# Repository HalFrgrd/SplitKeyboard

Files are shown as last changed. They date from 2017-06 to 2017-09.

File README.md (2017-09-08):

# SplitKeyboard

This is a split DIY custom keyboard loosely based on:
  * Ultimate Hacking Keyboard (interlocking ability)
  * General ten key less design
  * Preonic (I liked how the bottom row was nearly all 1u)

It is also interlocking with magnets to snap it together.
There are thumb arrow keys.
[See here for images](http://imgur.com/a/XaVwF)

**Table of Contents**  *generated with [DocToc](http://doctoc.herokuapp.com/)*

  - [How a split keyboard connects both halves](#how-a-split-keyboard-connects-both-halves)
    - [Basic concepts](#basic-concepts)
    - [Wiring between the two halves](#wiring-between-the-two-halves)
  - [Sourcing your parts](#sourcing-your-parts)
  - [Build guide](#build-guide)
    - [Designing and planning](#designing-and-planning)
    - [Putting it together](#putting-it-together)
      - [General assembly](#general-assembly)
      - [Wiring](#wiring)
  - [Custom firmware](#custom-firmware)
  
### How a split keyboard connects both halves
#### Basic concepts
While researching, I didn't find a comprehensive guide on split keyboard concepts.
These are the ways I learnt it could be done:
  * Having a controller (Teensy or an Arduino) in one half and an IO expander in the other half.
  * Having two controllers, one in each half which communicate via one of two protocols:
    * Serial or
	 * I2C
  * One controller and a bunch of wires between the halves

Controller + IO expander: The way the wiring in any keyboard works is that each row and each column is wired individually to a pin on somekind of controller. Say you have a controller with 20 available pins, your keyboard can have at most 100 keys as you can have 10 rows and 10 columns. If you want more keys, you use and IO expander. An IO expander has a bunch of pins for wiring the rows and columns to and a few special pins that are wired to the controller on the other half of the keyboard. Only two pins are used for communication between the IO expander and the Arduino. special pin condenses all the other pins and can pass all the information from the pins to the controller. So you can have a controller in one half and an IO expander in the other and have only a few wires between the two halves.

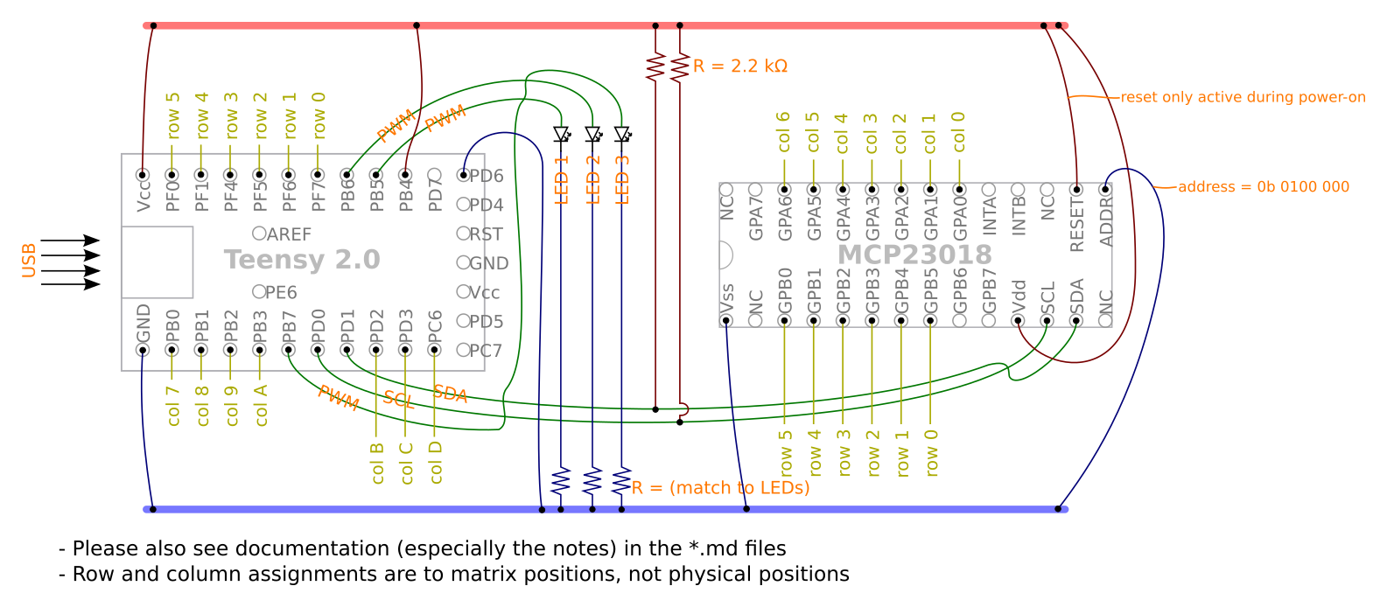
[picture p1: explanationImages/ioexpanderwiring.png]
wiringioexpander


Two controllers: In this method, each half has a controller. The second controller (the one that isn't plugged directly into the computer) acts like a more versatile IO expander. I say more versatile because you can plug the secondary half into the computer or use both halves independently. It can act as a controller when you want it to. I believe that the firmware on the secondary half is used only to forward the signals on to the other half and the keymap that is on this secondary controller doesn't get used. But when you have it plugged into the computer separately, it runs the keymap that you programmed to it. So when it is being used as a secondary half it can behave in one way, but if you use it one its own, it might act as a numpad (or any other custom keymap).

If you have a controller in each half, you have to decide how they communicate with each other; what communication protocol do they use. I have learnt that the two main ones are Serial and I2C. Sparkfun does a great beginner friendly in depth look at them: [serial](https://learn.sparkfun.com/tutorials/serial-communication) and [I2C](https://learn.sparkfun.com/tutorials/i2c). On a side note, Sparkfun tells you a list of suggested topics before reading the chosen topic, so if you want to learn more about the electronics involved, start on Sparkfun. Without going in depth, the main differences are:
  * Serial uses 3 wires and I2C uses 4 (more about this in the next topic)
  * I2C is faster (but not noticeably because no one types that fast)

This is the method I used because an IO expander was going to be about the same cost as another Arduino. I also used serial just because it was easier working with 3 wires. Wiring for both serial and I2C can be found [here](#wiring)

The last (and least 'clean') method is just to have a lot of wires going between the sides. For instance, all the switches in a row on one side would be connected to a wire that goes between the halves and connects to all the switches on that half and then to the controller. 

The method you will affect the choice in wires that you have to make.
#### Wiring between the two halves
For the first two methods listed above, you will need a maximum of 4 wires:
  * One for ground
  * One for power
  * One/two for communication depending on protocol.

These are low power wires so pretty much any kind of cable can be used. A popular choice is an AUX cord. These are broken up into Tip Ring Sleeve (TRS, 3 internal wires) and Tip Ring Ring Sleeve (TRRS, 4 internal wires) cables: 

<p = align="centre">

</p>

You can identify them on eBay and other places by just looking at the pictures (3 notches or 4 notches). I went with a TRRS cable because I wasn't sure if I wanted to use I2C, but just go with TRS because there is wider variety of colours and more availability. If you want to be considered a pro mechanical keyboard user, get a braided cable that matches your keycap colour scheme :). You will also want a jack on either half of your keyboard so you can easily plug and unplug your cable and TRS jacks are a lot easier to find. Don't be fooled by jacks having 4 or 5 pins as 2 or 3 of them will be connected to the same part of your cable and are just extra pins. TRRS cables are compatible with TRS jacks. I would recommend getting a curly cable as it will look better and reduce clutter on your desk. After all, half of having a split mech keyboard is making your desk layout good (peep [mechanicalheadpens](https://www.reddit.com/r/mechanicalheadpens/))

You can use any other type of cable. I've seen SATA cables or RJ45 cables being used. You have to consider the height of the jack. If its too tall you'll have to make your case taller which isn't ideal. TRS jacks tend to be low profile and cheap which make them popular. My TRS jacks were still quite tall (8mm in a 9mm interior case) so if I were to design one again, I would use a USB C or micro USB breakout board: 
<p = align="centre">

</p>

If you want to not bother with those two methods and have many wires going inbetween the halves, I would recommend a ribbon cable. You can probably rip one out of an old computer or printer. It should enough wires for `Number of rows` + `Number of columns` + `2 for power`. I have never tried nor seen, but I think a USB C cable with a breakout board on either end would be quite elegant. USB C has 24 wires.

### Sourcing your parts

This is the shopping I had:
  * Materials:
    * 2 Arduino Pro Micros
    * 91 key switches
    * Stabilizers
    * Keycaps
    * 2 TRS jacks
    * 1 curly TRRS cable 
    * 91 1N4148 Diodes (200 pack)
    * 3 sheets of 400x300mm clear acrylic (3mm thick)
    * 24 2mm heigh, 4mm diameter magnets
    * 12 3mm nuts and bolts (20mm long)
    * A fair amount of solder
    * Around 2m of wire (thinner the better)
    * Extras:
      * Rubber feet
      * Nylon screws
    * If using I2C: 2 4.7kΩ pull up resistors
  * Tools:
    * Soldering iron with thin tip
    * Needle nose pliers come in handy

Everything I don't mention below, I bought on eBay.

I am living in Australia so I bought stabilizers and key switches from [mechkb.com](https://mechkb.com/). The key switches were 120 Gateron Browns. I would go for these ones if you are unsure because they are not too clicky but still have a satisfying tactile bump.

Keycaps were from [Banggood](https://www.banggood.com/) (white dual shot). I made sure that my key layout could be adapted from a standard 104 keyset. To do this I compared the summary table on [keyboard layout editor](http://www.keyboard-layout-editor.com/#/) for my keyboard and the standard 104 ANSI layout.

The choice of case material is important. The key switches are designed to snap into 1.5mm material. But 1.5mm acrylic is too floppy even when used in a half-keyboard wide case. I think the optimal material would be 1.5mm aluminium as steel of this thickness is said to be too hard and can fatigue your fingers. I used 3mm clear acrylic as the place where I laser cut it (explained in the build guide) had it in stock and wouldn't cut metal. Note that you will have to hot glue or secure the switches to the acrylic if using 3mm as I explain in the build guide. Don't worry if you want to rebuild your keyboard later because hot glue can easily be torn off the switches using some pliers. I have replaced a switch that was glued in and could easily get all the glue off the switch and the plate.

The guidance is different if you are using a PCB as the PCB holds the switches in place much better than a 3mm plate. I chose against using a PCB because: it was added cost; I would not have the option the modify or repair the keyboard easily; and it means more waiting time if you decide to order it.

This is how much it will cost:

| Items | Cost (Aus Rupees)| Cost (USD) |
| --- |:---: | ---:|
| Arduinos | 26 | 20 |
| Switches | 56 | 43 |
| Stabilzers | 11 | 8 |
| Keycaps | 21 | 16 |
| TRS Jacks | 4 | 3 |
| AUX Cable | 5 | 4 |
| Diodes | 8 | 6 |
| Acrylic | 30 | 23 |
| Magnets | 4 | 3 |
| Wire | 5 | 4 |
| **Total** | 170 | 129 |

I could have saved mainly on the Arduinos but I wanted some from inside Australia because I didn't want to wait forever and buy them from China. If you want you could also 3D print the keycaps and use MDF instead of acrylic.

### Build guide
#### Designing and planning
This was my favourite part of the process. Explore the subreddits, forums, and Pinterest and find designs that you like. Afterwards, got to [Keyboard Layout Editor](http://www.keyboard-layout-editor.com/#/). This website allows you to completely plan your keyboard layout either from scratch or from a preset. This is where you will find your summary table so that you know the sizes and number of keycaps you need. Also, under the raw data tab you will find the layout in an array. This is used by the next website, [SwillKB Builder](http://builder.swillkb.com/), to generate the case and switch plate. The website has its own detailed documentation in the blue question marks, but this is how each one of the options you need to fill in works:

1. Plate Layout: You copy and paste your raw data into the Plate Layout box. The raw data contains all the spacing and positions of the key switches which is used to generate the switch plate and size of the case.
2. Switch Type: The two main types of switches are Cherry and Alps. Gaterons are clones of Cherry's so just used type 1 (the square ones).
3. Stabilizers: There are two main types of stabilizers (used to stabilize keys >= 2u): Cherry and Costar. I used the Cherry + Costar type as I didn't know what to go with and this option allows both.
4. Case Type: You probably want sandwhich as this is custom made to your keyboard.
5. USB Cutout: I turned this off as I wanted one in each half. I edited the files afterwards and put one in each half.
6. Mount Holes: I turned this off as I used the polygon tool to have more control over where the holes should go.
7. Edge Padding: I used 4mm on all sides.
8. Plate Corners: What radius do you want the corners to be.
9. Custom Polygons: This allows you to put in custom shapes where you want. It's a good feature because editing 5 files afterwards can be a pain. I used their example to get nice looking mount holes that come out of the sides of the case.
10. Kerf: I didn't use this feature as I was laser cutting and the key switches were a good fit. 
11. Line Color: I didn't bother with this as I was going to edit the files afterwards. Some laser cutters use specific colours to know when to cut and when to engrave.
12. Line Weight: Some laser cutters will see the line as a rectangle that needs multiple passes if the line is too thick. I left this blank as I was going to edit the files after. 

The way I generated the files for my split keyboard was by making a [normal unsplit keyboard on KLE](http://www.keyboard-layout-editor.com/#/gists/94c5c17f0c58b8debc7f5c045de34edd) and on SwillKB Builder. I then used Inkscape to manually put in a line where I wanted the split to be. This way I could get a nice interlocking split keyboard.

I saved the files as SVG files as I knew how to edit them on Inkscape. The modifications I made to the case plans from SwillKB were:
1. Adding a line where I wanted the keyboard to be split. This made the acrylic quite thin near the split line but it was layered up so it was strong enough.

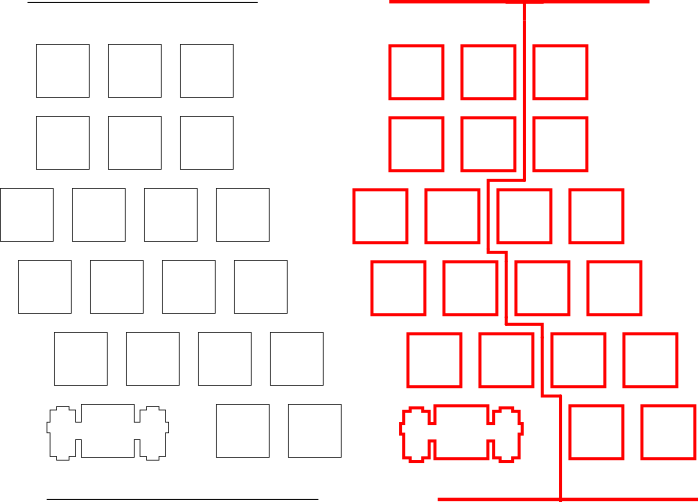
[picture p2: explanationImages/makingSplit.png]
splitline


2. Adding more mount holes. I needed some more as I essentially cutout a segment between where the Arduino and the TRS jack.

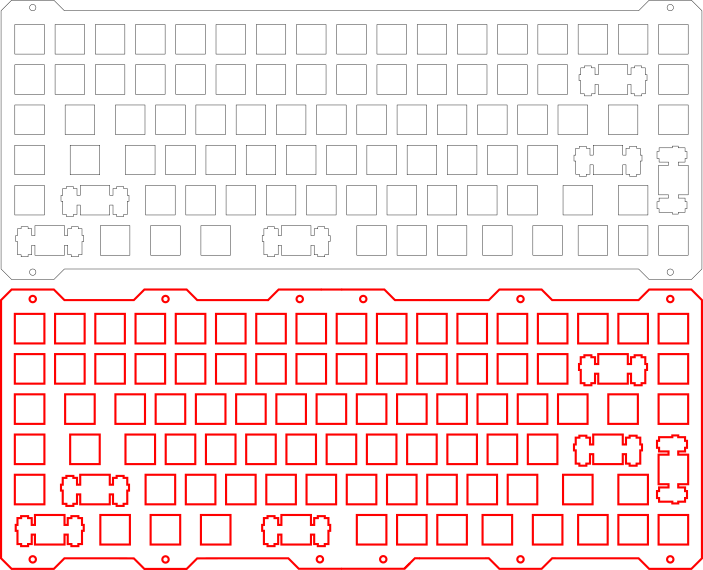
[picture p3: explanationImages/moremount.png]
mountholes


3. Adding little pockets for the magnets to fit in. I chose to have 6 magnets in pocket so that I would use all of the magnets that I bought. The magnets were to sit in the three middle layers, so I didn't modify the bottom and top layers for this step:

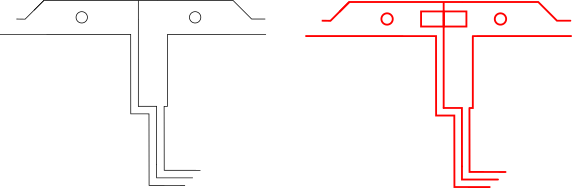
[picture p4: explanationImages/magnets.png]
magnets


4. Adding cutouts on the necessary layers for the Arduino and TRS jack. The Arduino was 4mm thick I just modified the two lower middle layers. The TRS jack was 8mm thick so I modified all three middle layers.

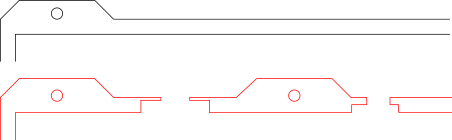
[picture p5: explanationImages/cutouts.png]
cutouts


I planned my cutouts so that I could secure the TRS jack in place using the ring screw:

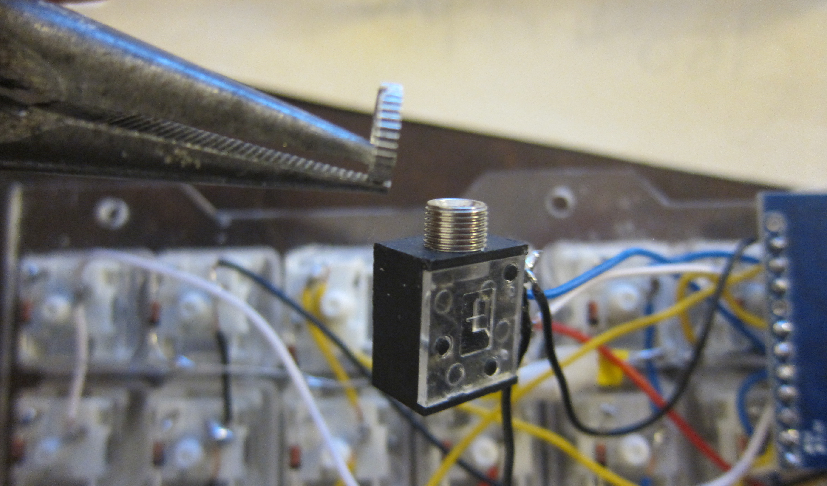
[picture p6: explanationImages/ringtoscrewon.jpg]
ringscrew


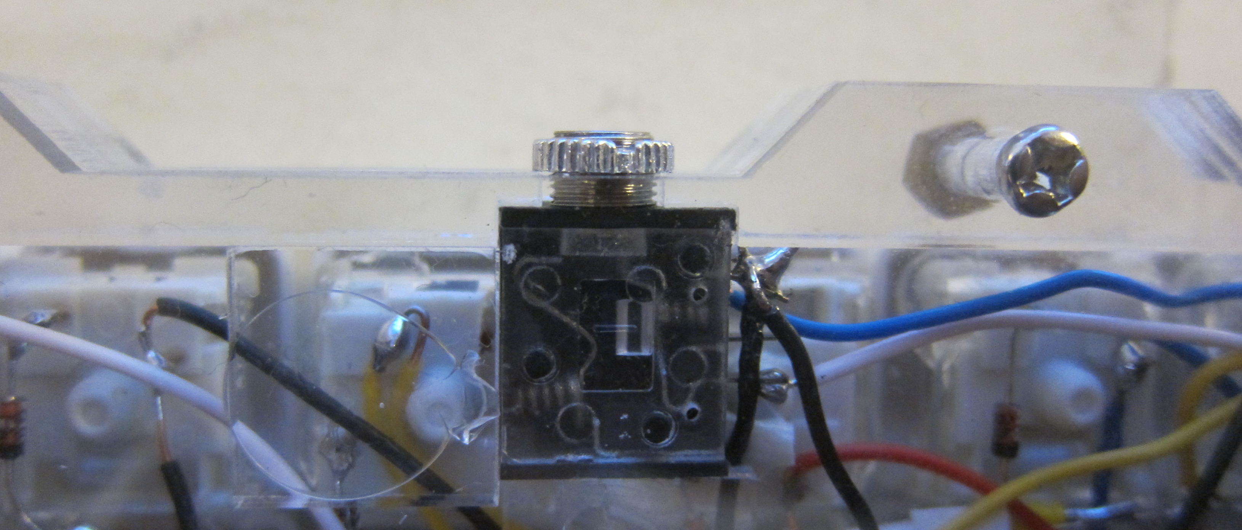
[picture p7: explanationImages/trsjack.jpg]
ringscrewagain


I laser cut the case at a FabLab. This a community diy centre with 3D printers and a laser cutter. The laser cutter was $5 per use and you could buy material there.

#### Putting it together
##### General assembly
I would follow [Matt3o's guide](https://deskthority.net/workshop-f7/brownfox-step-by-step-t6050.html) for the soldering and installation of the switches, and wiring of the controller.
Notes from this guide:
  * Use lots of hot glue when you secure the switches down because if you are pulling off keycaps, you don't want to pull off the key switch with it.
  * The orientation of the switches doesn't matter at all which comes in handy when you want to fit in a TRS jack. As the TRS jacks were quite tall they would have caused some got the switches to be pushed back up as there wasn't enough room for both the switches ans the jack. I had to cut part of the bottoms off two switches and rotate them a bit so that everything fitted in the case. There is quite a lot of unused space in the switches so you can cut nearly all the bottom plastic housing off without compromising functionality. Here you can see the switches that I cut:

cutswitches

  * I didn't use a micro USB cable inside the case as I didn't think it was necessary. The cable from the computer plugs directly into the case. As seen: 

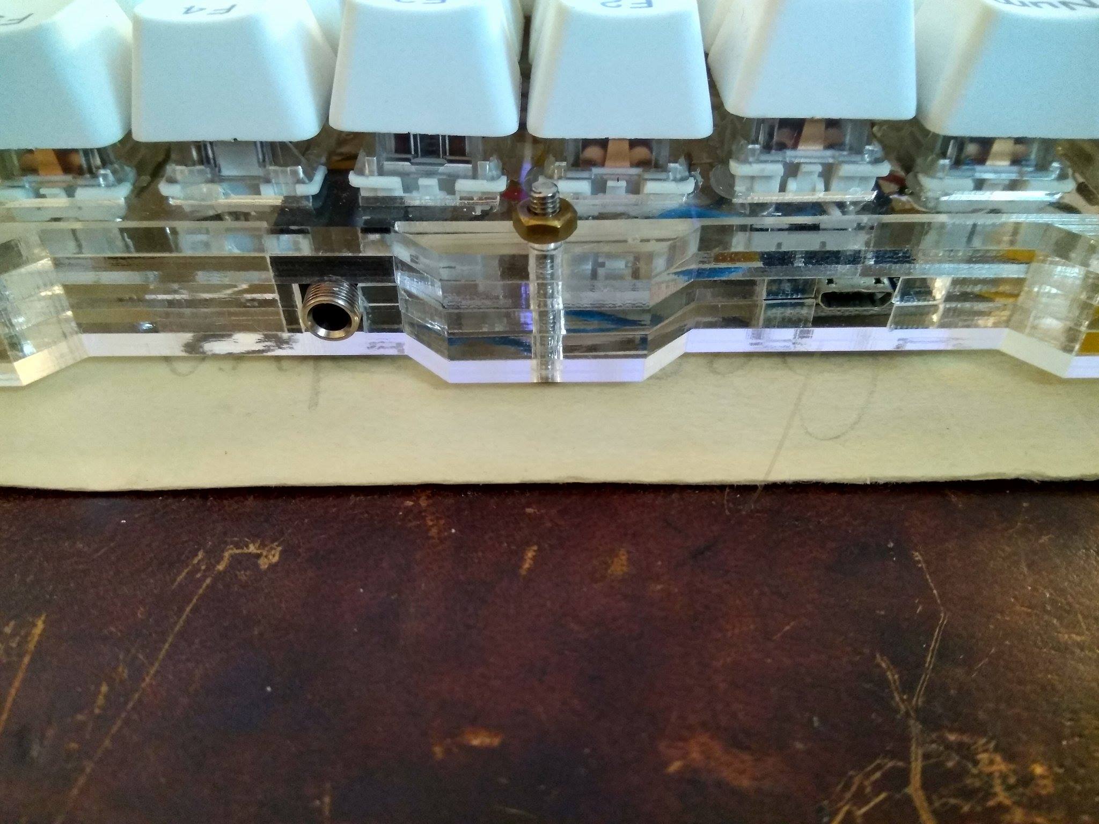
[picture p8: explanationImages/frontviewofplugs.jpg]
frontview


  * It is quite tight having the Arduino directly under the switches so keep your wires short and tidy. Otherwise like Matt3o, you can fit the controller under the space bar. I glued a couple of the acrylic switch cutouts to the bottom layer so that the Arduino would be held in place:

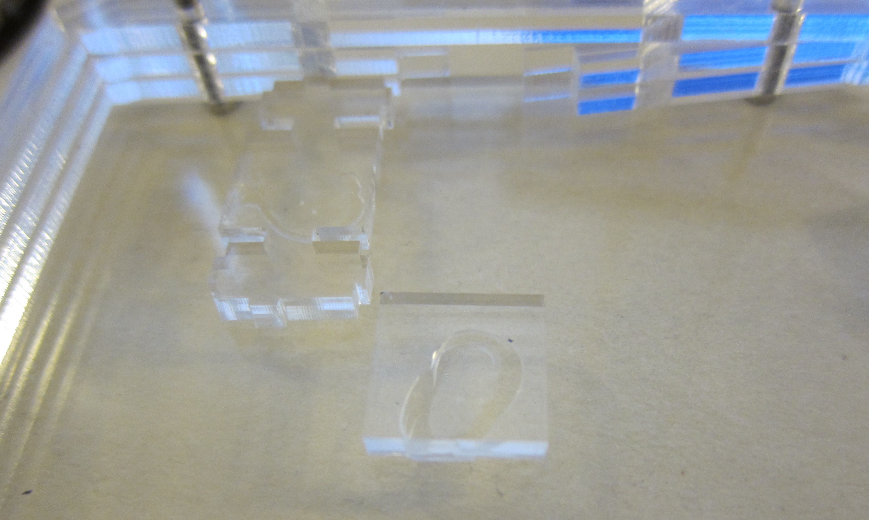
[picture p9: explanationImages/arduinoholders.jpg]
arduinoholder


  * I soldered wires to the RST and GND pins and pushed the ends through the LED slot on the a switch near the edge of the keyboard. I hot glued them in place. This is so I can easily put the Arduino into bootloader mode. I will explain more about this in the firmware section. The ends of the wires is shown:

resetwires

  * I was using magnets so that the two halves would stick together. I put some hot glue where the magnets should be and squished them in. As seen:

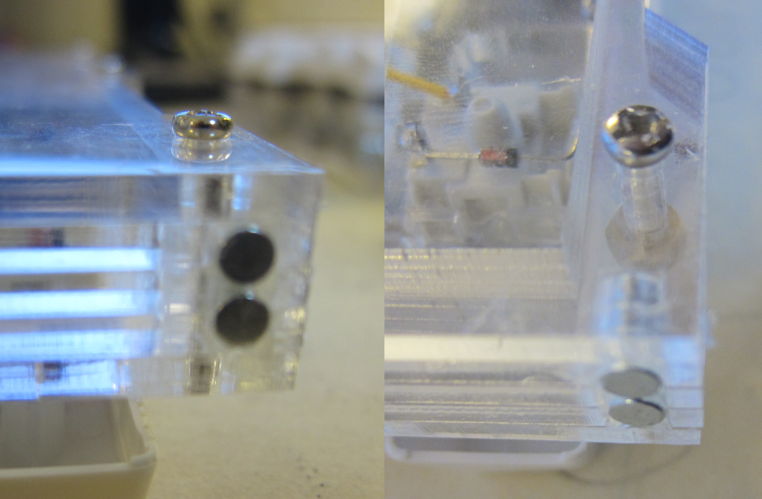
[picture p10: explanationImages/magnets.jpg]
magnets


With the bits of the acrylic that were left over from the middle layers and some from a first prototype, I made a palmrest:
palmrest

##### Wiring
I would first start by wiring the two halves together. This is the wiring for serial:

serialwiring

And this is the wiring for I2C:

i2cwiring

You wire these wires to the pins on your jack and use the identical pins on the jack of the other half.

Then you can wire the columns and rows like Matt3o shows to any of the input / ouput pins. Searching for a pin out diagram for your controller will help:

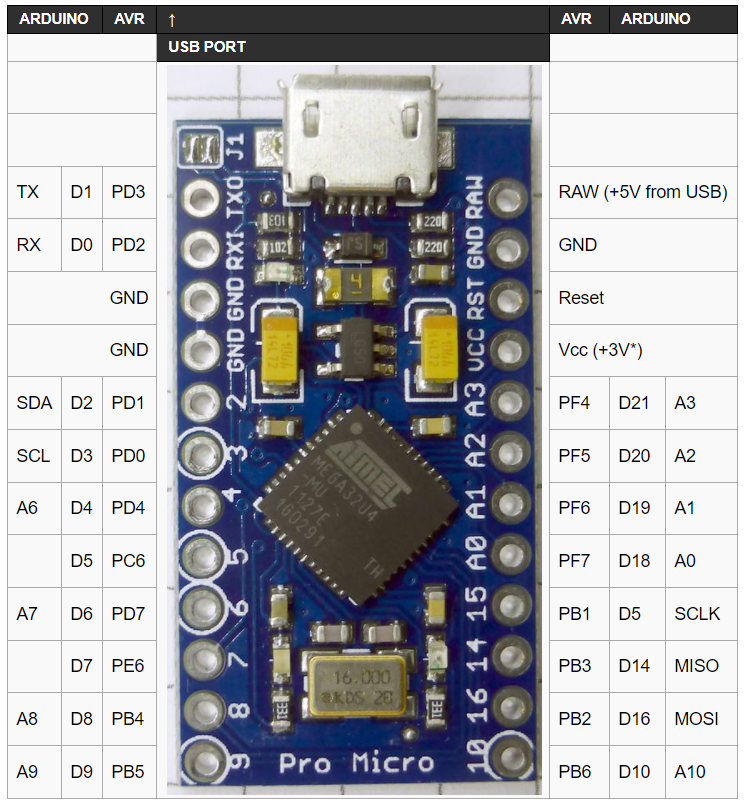
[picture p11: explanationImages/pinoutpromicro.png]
pinoutpromicro


You don't have to use the exact same pins on the controller for each half, but it is easier if you do. I would make a table like this whilst you are wiring to your pins as you will use it later (Note: QMK pin naming (for example) uses B2 instead of PB2):

```
          ,------------------------------------------------------------------------------------------------------------------------------.
  PF5(A2) | Esc  | blkn |   f1 |   f2 |   f3 |  f4  |  f5  |  f6  |   no |  f7  |  f8  |   f9 | f10  |  f11 | f12  | voldn| volup| mute  | PD1
          |------+------+------+------+------+-------------+------+------+------+------+------+------+------+------+------+------+-------|
  PF6(A1) | blkn | grv  |   1  |    2 |    3 |   4  |   5  |   6  |   no |   7  |   8  |    9 |   0  |  -   |   =  | no   | bksp | del   | PF4
          |------+------+------+------+------+-------------+------+------+------+------+------+------+------+------+------+------+-------|
  PF7(A0) | blkn | tab  |   q  |    w |    e |   r  |   t  |   no |   no |   y  |   u  |    i |   o  |  p   |   [  |  ]   |   \  | prtsc | PF5
          |------+------+------+------+------+-------------+------+------+------+------+------+------+------+------+------+------+-------|
     PB1  | blkn | cpslk|   a  |    s |    d |   f  |   g  |   no |   no |   h  |   j  |    k |   l  |  ;   |   '  | no   | enter| no    | PF6
          |------+------+------+------+------+-------------+------+------+------+------+------+------+------+------+------+------+-------|
     PB3  | blkn |lshift|   z  |    x |    c |   v  |   b  |   no |   no |   n  |   m  |    , |   .  |  /   |   no |rshift| upar | blkn  | PF7
          |------+------+------+------+------+-------------+------+------+------+------+------+------+------+------+------+------+-------|
     PB2  | lctr | gui  |  alt | larr |   no |  spc |  no  |   no |   no | uparr| dwnar| rarr |  fn  |  no  | meta | larr | dwnar| rarr  | PB1
          `------------------------------------------------------------------------------------------------------------------------------'
             PD1    PD4     PC6   PD7    PE6    PB4    PB5    PB6     F4 |   PD4    PC6   PD7    PE6    PB4    PB5    PB6     PB2   PB3
```

RGB LED stuff: [this tutorial seems quite good](https://github.com/nicinabox/lets-split-guide/blob/master/rgb-underglow.md) but I never did RGB LED stuff.

### Custom firmware 

I used QMK for the firmware. The installation is well documented by [QMK](https://docs.qmk.fm/). I would read through the documentation as it will help a lot in understanding what is going on. It's very easy to use of you are using a kit as there are all the common kits (Ergodox, Let's Split). If you have an unsplit keyboard you can run the following command from root to get a new project setup:

`$ ./util/new_project.sh nameofnewproject`

But if you have a fully custom split, I would recommend modifying the Let's Split folder as I couldn't figure out how to add split functionality to the blank keymap. When modifying the Let's Split firmware there are a few files you need to edit:

  * /lets_split/keymaps/copyanotherkeymapfolder/config.h

    Here you can use `#define USE_SERIAL` or `#define USE_I2C`
  * /lets_split/keymaps/copyanotherkeymapfolder/keymap.c

    This is where you get to define all the layers you will have on your keyboard and what all the keys do. Read the [documentation](https://docs.qmk.fm/) if you haven't as this explains how to make a good keymap. Also there is an active subreddit [r/olkb](https://www.reddit.com/r/olkb/) if you have more questions.
  * /lets_split/rev2/config.h

    Edit the `#define MANUFACTURER` and other definitions to whatever you like.

    `#define MATRIX_ROWS` should be the number of total rows. e.g. 5 in the left and 7 in right would mean `#define MATRIX_ROWS 12`

    `#define MATRIX_COLUMNS` should be the number of total columns. e.g. 6 in the left and 7 in right would mean `#define MATRIX_COLUMNS 13`

    I used seperate pins in each half so when I built the firmware for the left side I would uncomment the first two lines and comment the last two:

    ```
    // #define MATRIX_ROW_PINS { F5, F6, F7, B1, B3, B2} //leftside
    // #define MATRIX_COL_PINS { D1, D4, C6, D7, E6, B4, B5, B6, F4 } //leftside
    #define MATRIX_ROW_PINS { D1, F4, F5, F6, F7, B1} //rightside
    #define MATRIX_COL_PINS { B3, B2, B6, B5, B4, E6, D7, C6, D4 } //rightside
    ```

  * /lets_split/rev2/rev2.h

    This file has definitions about the layout of the keyboard so that the keymap file can be used. The main thing to do is to change the definitions for KEYMAP or KC_KEYMAP so that it matches your layout (i.e. the correct number of rows and columns) or you will get errors when building.

All these files are located in the [lets_splitFirmware](./lets_splitFirmware/) folder if you want to look at them.

Once you have succesfully edited those files, it is time to build (AKA compile) your keymap. I would recommend making a `Makefile` file in your keymap directory like I have done [here](./lets_splitFirmware/keymaps/hfvoy/). This makes it easier to compile just your keymap and not all the others. The documnentation goes much more in depth about building using the `make` command. Go to your keymap directory and run the `make` command. This will either spew out errors that you need to deal with, or will create a `hex` file in the qmk root folder. Now that you have compiled your firmware, it is time to flash it.

When flashing the firmware onto the Arduino's, they must in "bootloader mode". The Arduino's can either run the program on them, or be in a mode where they rewrite their memory using whatever the computer passes them; this is bootloader mode. When you first buy an Arduino, they are in bootloader mode but when you want to re-flash them they need to be put back into bootloader mode. This is done by quickly connecting the RESET and GROUND pins. Some people to connect these pins to a small button and have that on the outside of the case. I chose to have two wires protruding through the LED slot on a switch. I can take the keycap off, and quickly connect the two wires. Much easier than having to disassemble the case to get to the Arduino. I re-flashed my Arduino's around 20 times so it's worth considering how you will short the two pins.

On Windows, I found the best program for flashing was AVRDUDESS. [This guide](https://gist.github.com/CampAsAChamp/e747d2b605c0c32923593b529f82ccdd) was great at explaining how to install and flash using AVRDUDESS.

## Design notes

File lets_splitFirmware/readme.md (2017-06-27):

Let's Split
======

This readme and most of the code are from https://github.com/ahtn/tmk_keyboard/

Split keyboard firmware for Arduino Pro Micro or other ATmega32u4
based boards.

## Build Guide

A build guide for putting together the Let's Split v2 can be found here: [An Overly Verbose Guide to Building a Let's Split Keyboard](https://github.com/nicinabox/lets-split-guide)

There is additional information there about flashing and adding RGB underglow.

## First Time Setup

Download or clone the whole firmware and navigate to the keyboards/lets_split directory. Once your dev env is setup, you'll be able to generate the default .hex using:

```
$ make rev2
```

You will see a lot of output and if everything worked correctly you will see the built hex files:

```
lets_split_rev2_serial.hex
lets_split_rev2_i2c.hex
```

If you would like to use one of the alternative keymaps, or create your own, copy one of the existing [keymaps](keymaps/) and run make like so:

```
$ make rev2-YOUR_KEYMAP_NAME
```

If everything worked correctly you will see a file:

```
lets_split_rev2_YOUR_KEYMAP_NAME.hex
```

For more information on customizing keymaps, take a look at the primary documentation for [Customizing Your Keymap](/readme.md##customizing-your-keymap) in the main readme.md.

### Let's split 1.0
If you have a first generation Let's Split you will need to use the revision 1 code. To do so, use `rev1` in all your commands instead.

Features
--------

For the full Quantum Mechanical Keyboard feature list, see [the parent readme.md](/readme.md).

Some features supported by the firmware:

* Either half can connect to the computer via USB, or both halves can be used
  independently.
* You only need 3 wires to connect the two halves. Two for VCC and GND and one
  for serial communication.
* Optional support for I2C connection between the two halves if for some
  reason you require a faster connection between the two halves. Note this
  requires an extra wire between halves and pull-up resistors on the data lines.

Required Hardware
-----------------

Apart from diodes and key switches for the keyboard matrix in each half, you
will need:

* 2 Arduino Pro Micro's. You can find theses on aliexpress for ≈3.50USD each.
* 2 TRRS sockets and 1 TRRS cable, or 2 TRS sockets and 1 TRS cable

Alternatively, you can use any sort of cable and socket that has at least 3
wires. If you want to use I2C to communicate between halves, you will need a
cable with at least 4 wires and 2x 4.7kΩ pull-up resistors

Optional Hardware
-----------------

A speaker can be hooked-up to either side to the `5` (`C6`) pin and `GND`, and turned on via `AUDIO_ENABLE`.

Wiring
------

The 3 wires of the TRS/TRRS cable need to connect GND, VCC, and digital pin 3 (i.e.
PD0 on the ATmega32u4) between the two Pro Micros.

Then wire your key matrix to any of the remaining 17 IO pins of the pro micro
and modify the `matrix.c` accordingly.

The wiring for serial:

serial wiring

The wiring for i2c:

i2c wiring

The pull-up resistors may be placed on either half. It is also possible
to use 4 resistors and have the pull-ups in both halves, but this is
unnecessary in simple use cases.

Notes on Software Configuration
-------------------------------

Configuring the firmware is similar to any other QMK project. One thing
to note is that `MATIX_ROWS` in `config.h` is the total number of rows between
the two halves, i.e. if your split keyboard has 4 rows in each half, then
`MATRIX_ROWS=8`.

Also the current implementation assumes a maximum of 8 columns, but it would
not be very difficult to adapt it to support more if required.

Flashing
-------
From the keymap directory run `make SUBPROJECT-KEYMAP-avrdude` for automatic serial port resolution and flashing.
Example: `make rev2-serial-avrdude`

Choosing which board to plug the USB cable into (choosing Master)
--------
Because the two boards are identical, the firmware has logic to differentiate the left and right board.

It uses two strategies to figure things out: look at the EEPROM (memory on the chip) or looks if the current board has the usb cable.

The EEPROM approach requires additional setup (flashing the eeeprom) but allows you to swap the usb cable to either side.

The USB cable approach is easier to setup and if you just want the usb cable on the left board, you do not need to do anything extra.

### Setting the left hand as master
If you always plug the usb cable into the left board, nothing extra is needed as this is the default. Comment out `EE_HANDS` and comment out `I2C_MASTER_RIGHT` or `MASTER_RIGHT` if for some reason it was set.

### Setting the right hand as master
If you always plug the usb cable into the right board, add an extra flag to your `config.h`
```
 #define MASTER_RIGHT
```

### Setting EE_hands to use either hands as master
If you define `EE_HANDS` in your `config.h`, you will need to set the
EEPROM for the left and right halves.

The EEPROM is used to store whether the
half is left handed or right handed. This makes it so that the same firmware
file will run on both hands instead of having to flash left and right handed
versions of the firmware to each half. To flash the EEPROM file for the left
half run:
```
avrdude -p atmega32u4 -P $(COM_PORT) -c avr109 -U eeprom:w:eeprom-lefthand.eep
// or the equivalent in dfu-programmer

```
and similarly for right half
```
avrdude -p atmega32u4 -P $(COM_PORT) -c avr109 -U eeprom:w:eeprom-righhand.eep
// or the equivalent in dfu-programmer
```

NOTE: replace `$(COM_PORT)` with the port of your device (e.g. `/dev/ttyACM0`)

After you have flashed the EEPROM, you then need to set `EE_HANDS` in your config.h, rebuild the hex files and reflash.

Note that you need to program both halves, but you have the option of using
different keymaps for each half. You could program the left half with a QWERTY
layout and the right half with a Colemak layout using bootmagic's default layout option.
Then if you connect the left half to a computer by USB the keyboard will use QWERTY and Colemak when the
right half is connected.

Notes on Using Pro Micro 3.3V
-----------------------------

Do update the `F_CPU` parameter in `rules.mk` to `8000000` which reflects
the frequency on the 3.3V board.

Also, if the slave board is producing weird characters in certain columns,
update the following line in `matrix.c` to the following:

```
// _delay_us(30);  // without this wait read unstable value.
_delay_us(300);  // without this wait read unstable value.
```

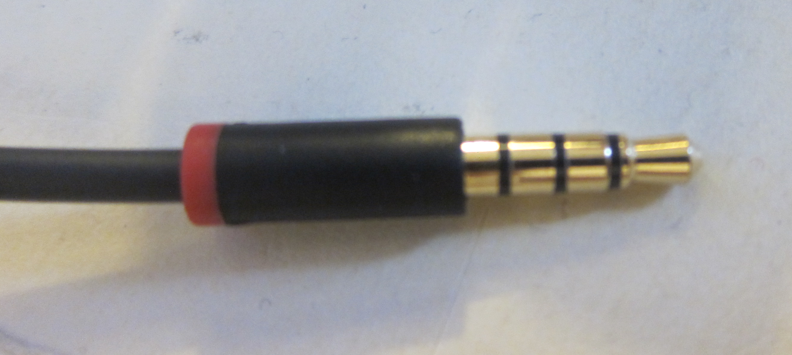
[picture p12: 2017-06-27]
explanationImages/trscableend.jpg

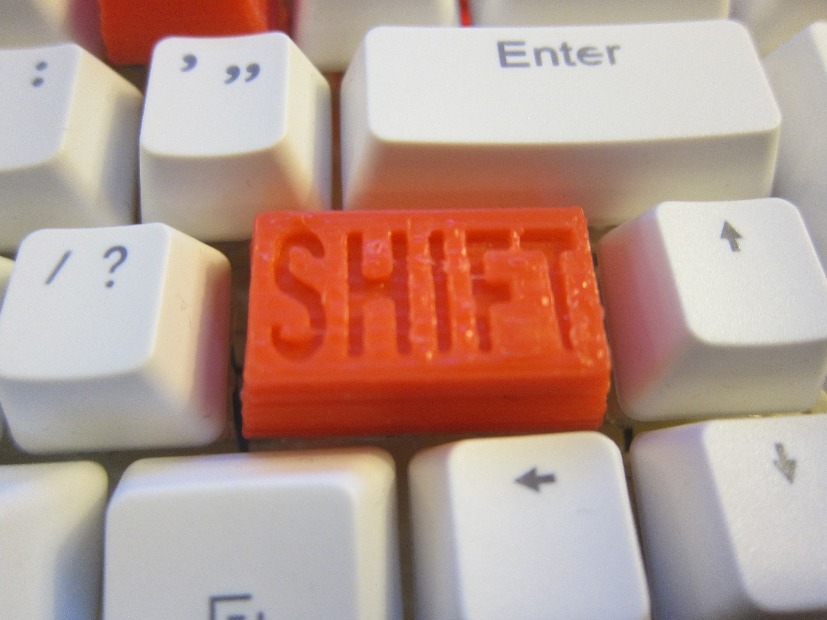
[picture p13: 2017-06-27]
explanationImages/shiftkey.jpg

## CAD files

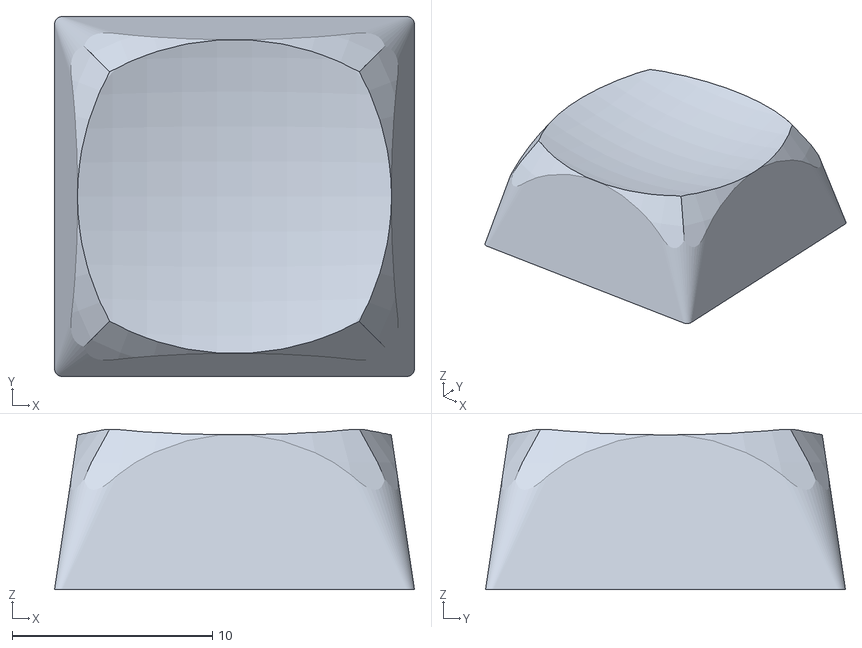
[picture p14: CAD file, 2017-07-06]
3DPrinting/dsakeycapbetter.stl
18.0 x 18.0 x 8.00

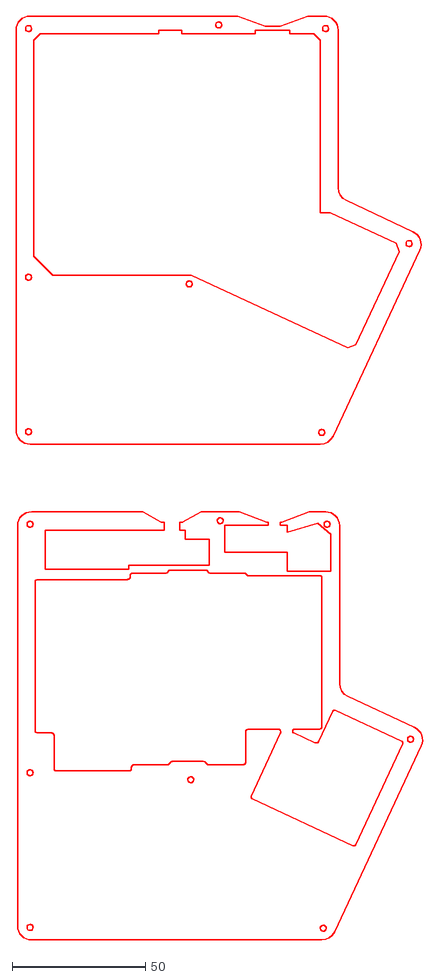
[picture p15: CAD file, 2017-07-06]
filesforergodoxcase/cuttinglefthandside.dxf
152.7 x 346.6

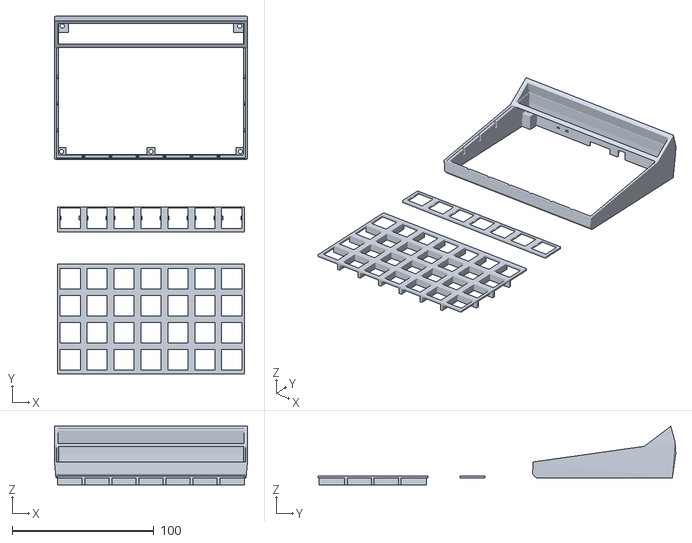
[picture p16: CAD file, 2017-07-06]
hfopt/case.stl
136.3 x 252.6 x 41.4

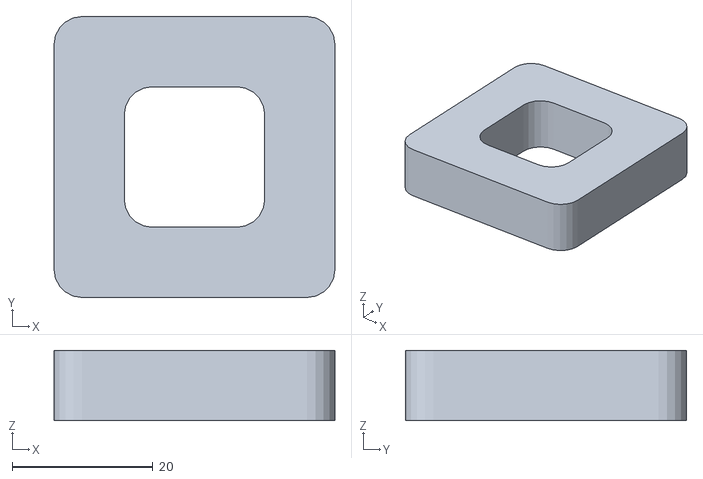
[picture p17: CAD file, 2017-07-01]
hfopt/obiscad-master/obiscad-master/STL/bcube_03_cutouts.stl
40.0 x 40.0 x 10.0

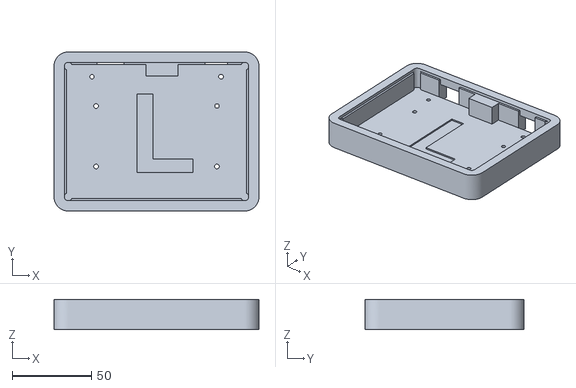
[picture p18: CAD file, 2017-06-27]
lets_splitFirmware/imgs/left.stl
129.2 x 100.2 x 19.1

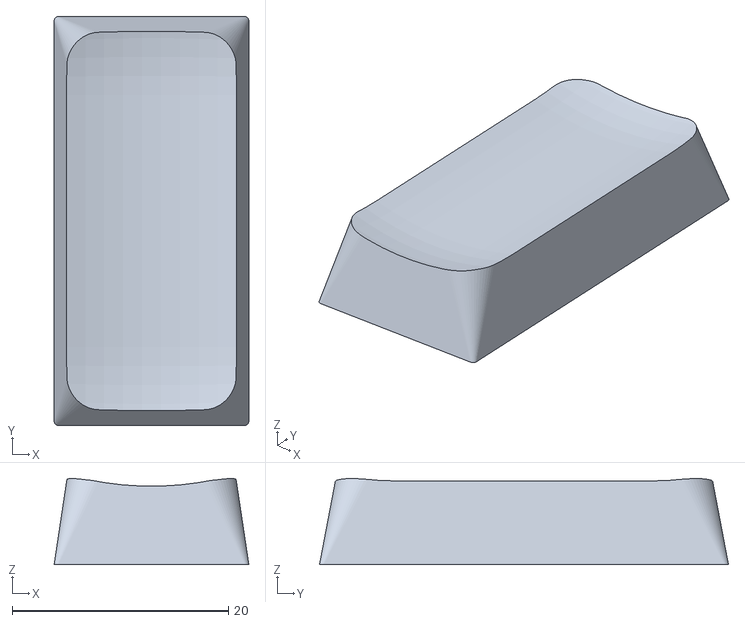
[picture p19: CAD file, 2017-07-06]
3DPrinting/dsakeycap.stl
18.0 x 37.8 x 7.95

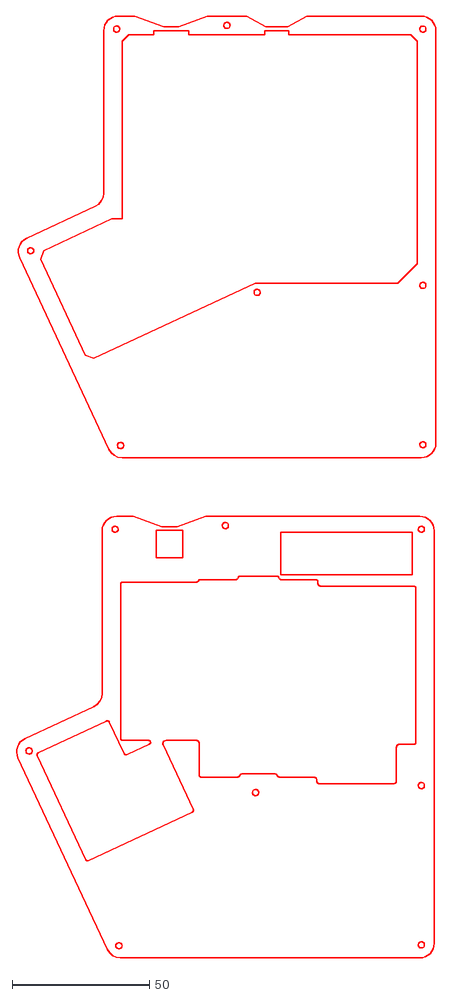
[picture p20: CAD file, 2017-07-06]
filesforergodoxcase/cuttingrighthandside.dxf
152.7 x 342.6

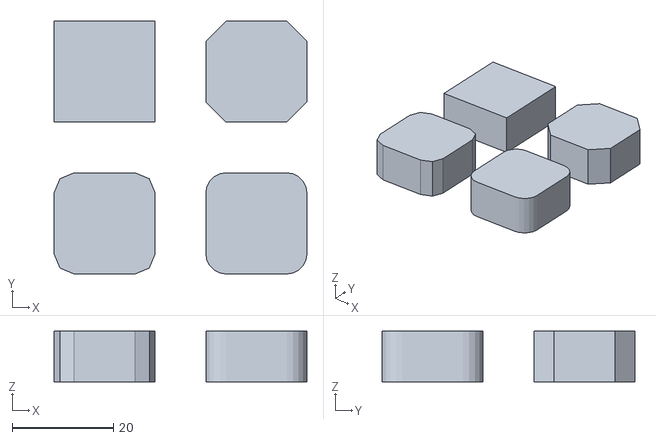
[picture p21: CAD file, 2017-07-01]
hfopt/obiscad-master/obiscad-master/STL/bcube_02_test_resolution.stl
50.0 x 50.0 x 10.0

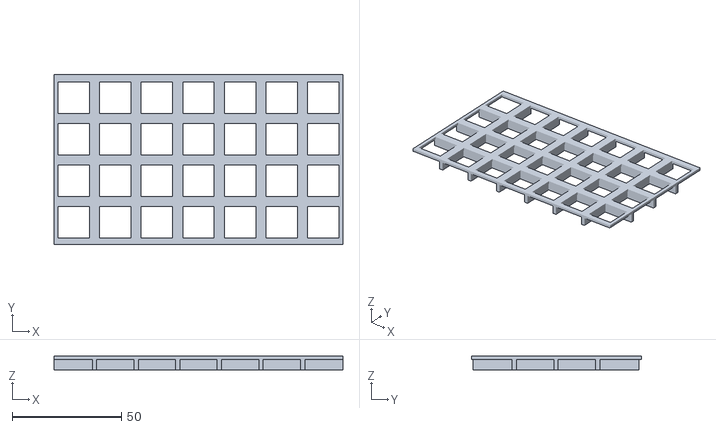
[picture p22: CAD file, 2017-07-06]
hfopt/Untitled-595a0afd.stl
132.3 x 77.7 x 6.40

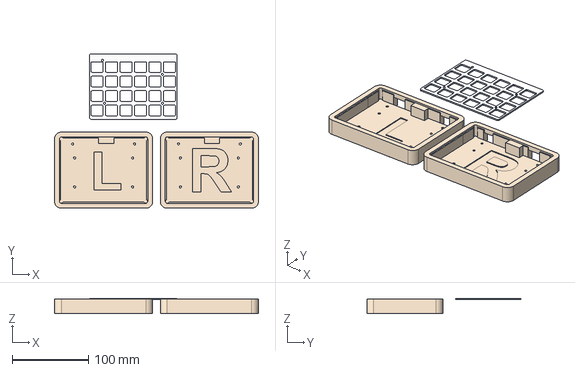
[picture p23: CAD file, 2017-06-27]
lets_splitFirmware/imgs/lets split rev2 case.iges
268.3 x 203.2 x 20.3 mm

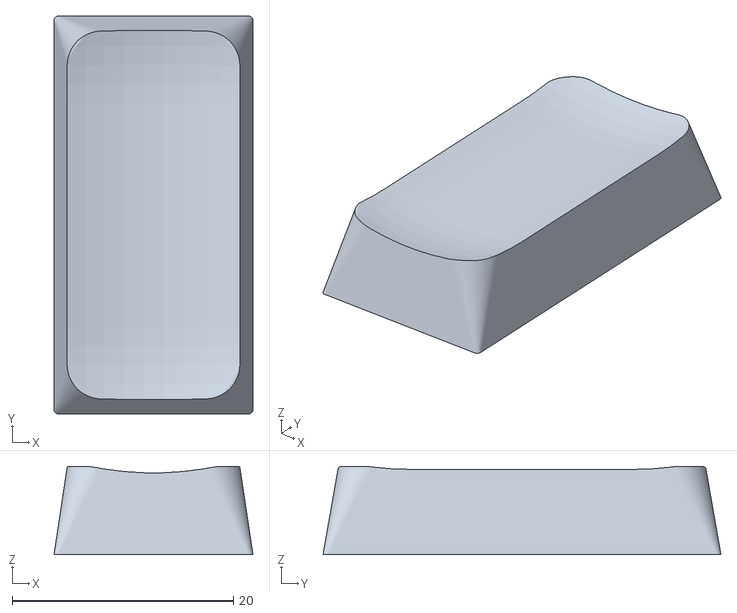
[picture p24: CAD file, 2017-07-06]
3DPrinting/dsakeycap2.stl
18.0 x 36.0 x 8.00

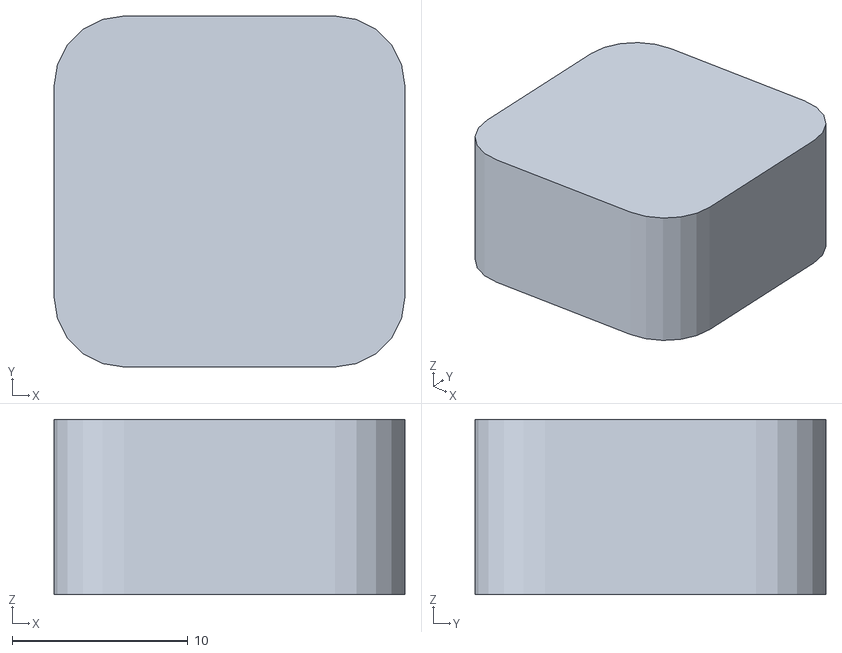
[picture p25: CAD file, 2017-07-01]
hfopt/obiscad-master/obiscad-master/STL/bcube_01_calibration_cube.stl
20.0 x 20.0 x 10.0

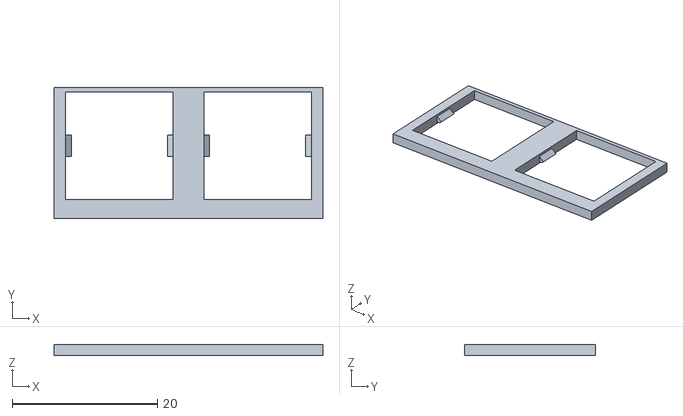
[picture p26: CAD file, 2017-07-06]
hfopt/Untitled-5959bd23.stl
37.0 x 18.0 x 1.50

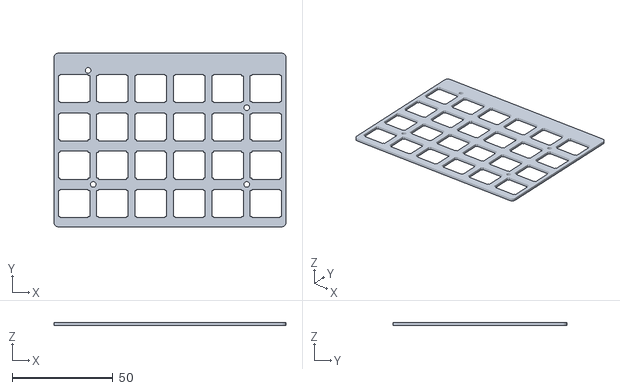
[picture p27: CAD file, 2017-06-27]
lets_splitFirmware/imgs/plate.stl
115.2 x 86.2 x 1.62

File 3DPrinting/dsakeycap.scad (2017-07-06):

lengthmultipl       = 2.1;
xdim                = 18;
ydim                = xdim*lengthmultipl;
xdimupper           = xdim-2.4;
ydimupper           = xdimupper*lengthmultipl;
lowercorner         = 0.4;
highercorner        = 3.04;
upperedgeradius     = 30;
sphericalindentation= 28;
roundingverticaledges = 19;
roundessxtrans      = 5;
roundessytrans      = roundessxtrans;
roundessztrans      = -4;
keystemheight       = 6;
distanceapartofkeystem = 14.00+5.05;
shorteningofspheresep = 5.5;
upperbaseyextension = 1;

module keystem() {
    totalheight=keystemheight+0.1;
    depthofcross=4.5;
    translationofcross = totalheight-0.5*depthofcross;

    widthstem = 4.40;
    lengthstem = 5.50;

    rotate([180,0,0]) translate([0,0,-totalheight]) 
    difference(){ //stemofkeycap
        
        //cylinder(h=totalheight,r=5.54/2,$fn=36);
        translate([-widthstem/2,-lengthstem/2,0]) cube([widthstem,lengthstem,totalheight]);
        union(){
            translate([0,0,translationofcross]) cube([1.35,4.10,depthofcross+0.5], center=true);
            translate([0,0,translationofcross]) rotate([0,0,90]) cube([1.35,5,depthofcross+0.5], center=true);
        }
}};




difference() { //make hollow    
    intersection() {
        *intersection_for(b = [0:90:359]) {
            rotate([0,0,b-45]) translate([roundessxtrans,roundessytrans,roundessztrans]) sphere(r= roundingverticaledges,$fn=60);
        };

difference() {//spherical indentation

    hull() {
        
        linear_extrude(height=0.001) hull() { //lower base
        square([xdim-lowercorner,ydim-lowercorner],center=true);

        translate([xdim/2-lowercorner,ydim/2-lowercorner,0]) circle(r=lowercorner, $fn=60);
        translate([-(xdim/2-lowercorner),ydim/2-lowercorner,0]) circle(r=lowercorner, $fn=60);
        translate([xdim/2-lowercorner,-(ydim/2-lowercorner),0]) circle(r=lowercorner, $fn=60);
        translate([-(xdim/2-lowercorner),-(ydim/2-lowercorner),0]) circle(r=lowercorner, $fn=60);
        };

         translate([0,0,8]) linear_extrude(height=0.001) hull() { //upper base
            //square([xdimupper-highercorner,ydimupper-highercorner],center=true);
             
             *intersection_for(n=[0:90:359]) {
                 rotate([0,0,n]) translate([upperedgeradius-xdimupper/2 + 0.3,0,0]) circle(r=upperedgeradius,$fn=800);
             };

            translate([xdimupper/2-highercorner,ydimupper/2-highercorner+upperbaseyextension,0]) circle(r=highercorner, $fn=60);
            translate([-(xdimupper/2-highercorner),ydimupper/2-highercorner+upperbaseyextension,0]) circle(r=highercorner, $fn=60);
            translate([xdimupper/2-highercorner,-(ydimupper/2-highercorner+ upperbaseyextension),0]) circle(r=highercorner, $fn=60);
            translate([-(xdimupper/2-highercorner),-(ydimupper/2-highercorner+ upperbaseyextension),0]) circle(r=highercorner, $fn=60);
        };
    };
    hull() {
        translate([0,(ydimupper-xdimupper)-shorteningofspheresep,sphericalindentation+ 8 - 0.9    -   0.5]) rotate([0,90,0]) sphere(r=sphericalindentation,$fn=100);
        translate([0,-(ydimupper-xdimupper)+shorteningofspheresep,sphericalindentation+ 8 - 0.9    -   0.5]) rotate([0,90,0]) sphere(r=sphericalindentation,$fn=100);
    }
};
};





hull(){
  translate([0,0,-0.1]) linear_extrude(height = 0.001) square([xdim-1.8,ydim-1.8],true);
  translate([0,0,keystemheight]) linear_extrude(height = 0.001) square([xdim-1.8-5,ydim-1.8-5],true);
};


};

translate([0,-distanceapartofkeystem/2,0]) keystem();
translate([0,+distanceapartofkeystem/2,0]) keystem();

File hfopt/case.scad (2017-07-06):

use <obiscad/attach.scad>
use <obiscad/vector.scad>


keyholeWidth            = 14.00;
biggerKeyholeWIdth      = 14.00 + 0.4;

gapBetweenSwitches      = 5.05;
matrixLength            = 5; //y axis
matrixWidth             = 7; //x axis
borderAroundEdge        = 1;
switchPlateDepth        = 1.5;
showfakekeycaps         = false;
//angledNumberLayer       = true;
//this the matrix width with the keyholes, gaps, and border.
matrixWidthGapsBorder   = matrixWidth*keyholeWidth + (matrixWidth-1)*gapBetweenSwitches + borderAroundEdge*2; 
matrixLengthGapsBorder  = matrixLength*keyholeWidth +(matrixLength-1)*gapBetweenSwitches + borderAroundEdge*2;
lowerFrameX             = matrixWidthGapsBorder+4; //controls the tapering of the general case
lowerFrameY             = matrixLengthGapsBorder+4;
lowerFrameHeight        = 0.001;
lowerFrameRecess        = 3;
middleFrameX            = matrixWidthGapsBorder+4;
middleFrameY            = matrixLengthGapsBorder+4+6;
middleFrameHeight       = 0.001;
upperFrameX             = matrixWidthGapsBorder+6;
upperFrameY             = matrixLengthGapsBorder+6+3;
upperFrameHeight        = 0.001;

angledNumberLayerWidth  = keyholeWidth + borderAroundEdge*2 +6 ;
angledNumberLayerLength = upperFrameX;

switchplatewidthpadding = 3;

angleforNumbered        = 30;
recessforNumbered       = 5;
recessforNumberedy      = 5;
secondpanelupwardsNumber= 6;

angleUpMid              = 8;
recess                  = 6;
trMid                   = [0,0,10];
trUpper                 = [0,0,trMid[2]+8.3];
roUpperMid              = [angleUpMid,0,0];

anumbered               = [ [-angledNumberLayerLength/2,-angledNumberLayerWidth/2,0] , [-1,0,0],    0  ];
cnumbered               = [ [trUpper[0]-upperFrameX/2, trUpper[1] + (upperFrameY/2-angledNumberLayerWidth) * cos(angleUpMid) +0, trUpper[2] + upperFrameY/2 * sin(angleUpMid) - angledNumberLayerWidth*sin(angleUpMid) ], [1,0,0], angleUpMid];

aswitchmain             = [ [0,-2.5,switchPlateDepth-0.1], [1,0,0],0];
cswitchmain             = [ [ 0 /*trUpper[0]-upperFrameX/2*/, trUpper[1] - upperFrameY/2 * cos(angleUpMid), trUpper[2] - upperFrameY/2 * sin(angleUpMid)], [1,0,0], angleUpMid];


aswitchnumbered         = [ [0,-3,+switchPlateDepth], [1,0,0],0];
cswitchnumbered         = [ [
                                0,//-angledNumberLayerLength/2,
                                -angledNumberLayerWidth/2 + (1-cos(angleforNumbered))*angledNumberLayerWidth*0.5 +0 ,
                                secondpanelupwardsNumber - sin(angleforNumbered)*angledNumberLayerWidth*0.5
                                ], [1,0,0],angleforNumbered];

debug                   = true;




if (debug){
   
    *connector(anumbered);
    *connector(cnumbered);
    
    *connector(aswitchmain);
    *connector(cswitchmain);

    *connector(aswitchnumbered);
    *connector(cswitchnumbered);
}

module arduinoShape() {
    heightOfArduino = 4;
    translate([0,matrixLengthGapsBorder/2,heightOfArduino/2 -0.1]) cube([19,30,heightOfArduino],center=true);
}

module trsJack(){
    heightOfTRS = 6;
    translate([20,matrixLengthGapsBorder/2,heightOfTRS/2-0.1]) cube([7,30,heightOfTRS],center=true);
}

module resetSwitchShape(){
    heightOfResetSwith = 2.7;
    translate([-40,matrixLengthGapsBorder/3,3]) union() {
    cube([heightOfResetSwith,30,heightOfResetSwith]);
    translate([8,0,0]) cube([heightOfResetSwith,30,heightOfResetSwith]);}
}


module buildKeyHole(keywidth=keyholeWidth,makesmallerforprinting=false) {
    if (makesmallerforprinting)
    {
        translate([0,0,-0.1])
        cube([biggerKeyholeWIdth,biggerKeyholeWIdth,switchPlateDepth+0.2]);
    } 
    else {
        translate([0,0,-0.1]) // this is because you can't have 0 width when doing difference
        cube([keywidth,keywidth,switchPlateDepth+0.2]);
    };
};
module littleknob() {
    //cube([1,1,1]);

    translate([0,0,0.5]) difference() {
            translate([0,0,-0.5]) intersection() {
                rotate([0,50,0]) cube([1,3,2],center=true);
                rotate([0,-50,0]) cube([1,3,2],center=true);
            }

            translate([-10,-10,+switchPlateDepth/2]) cube([20,20,20]);
            translate([-10,-10,-20-switchPlateDepth/2]) cube([20,20,20]);
        };

    };
    
module buildSwitchPlate(numberOfKeysWidth=matrixWidth,numberOfKeysLength=matrixLength,increaseTopEnd=0,buildsupports=false, buildknobs=false, makesmallerforprinting=false) {
    
    width = numberOfKeysWidth*keyholeWidth + (numberOfKeysWidth-1)*gapBetweenSwitches + borderAroundEdge*2 ;
    length = numberOfKeysLength*keyholeWidth +(numberOfKeysLength-1)*gapBetweenSwitches + borderAroundEdge*2  + increaseTopEnd ;
    
    translate([-width/2,0,0])
    
    difference(){
        union() {
        difference() {
            translate([-switchplatewidthpadding/2,-2,0])
            cube([
                width  + switchplatewidthpadding,
                length,
                switchPlateDepth
            ]);
            
            for(x = [1:numberOfKeysWidth]) {
                for(y = [1:numberOfKeysLength]) {

                    translations = [borderAroundEdge + (x-1)*keyholeWidth + (x-1)*gapBetweenSwitches - (biggerKeyholeWIdth- keyholeWidth)/2,
                    borderAroundEdge + (y-1)*keyholeWidth + (y-1)*gapBetweenSwitches - (biggerKeyholeWIdth- keyholeWidth)/2,
                    0];
                    
                
                    translate(translations) 
                    buildKeyHole(makesmallerforprinting=makesmallerforprinting);

                    
                };
            };
        };

        
        if(buildknobs){
        for(x = [1:numberOfKeysWidth]) {
                for(y = [1:numberOfKeysLength]) {
                    translate([
                        borderAroundEdge + (x-1)*keyholeWidth + (x-1)*gapBetweenSwitches + keyholeWidth/2,
                        borderAroundEdge + (y-1)*keyholeWidth + (y-1)*gapBetweenSwitches + keyholeWidth/2,
                        0.5]) 
                    //sphere(r=1,$fn=20);
                    union() {
                        if(makesmallerforprinting){
                        translate([-biggerKeyholeWIdth/2,0,0]) littleknob();
                        translate([+biggerKeyholeWIdth/2,0,0]) littleknob();  
                    }
                    }

                   

                    
                };
            };}

    if(buildsupports){
        for(x = [2:numberOfKeysWidth]) {
            for(y = [2:numberOfKeysLength]) {
                height=5;
                    
                        translate([
                        borderAroundEdge + (x-1)*keyholeWidth + (x-1)*gapBetweenSwitches - 5/2,
                        borderAroundEdge + (y-1)*keyholeWidth + (y-1)*gapBetweenSwitches - 5/2,
                        -height/2+0.1]) 
                        union() {
                            //cube([1,1,height],center=true);
                        cube([2,38,height],center=true);
                        cube([38,2,height],center=true);
                    }
                    
                };
            };
        };
    };

    if(makesmallerforprinting){
        translate([width/2,length+2,0]) cube([width+10,10,10],center=true);
        translate([width/2,0-7,0]) cube([width+10,10,10],center=true);
        translate([0-6,length/2,0]) cube([10,length+10,10],center=true);
        translate([width+6,length/2,0]) cube([10,length+10,10],center=true);
    }
    };
};

*buildSwitchPlate(buildsupports=true,makesmallerforprinting=true);

//The buildGeneralCase uses a hull on three rectangular frames (lower, middle, upper).

module buildNumberLayerAngled() {

    difference() {
        hull() {
            buildRectangularFrame(x=angledNumberLayerLength,y=angledNumberLayerWidth,z=0.001);
            translate([0,0,secondpanelupwardsNumber]) rotate([angleforNumbered,0,0]) buildRectangularFrame(x=angledNumberLayerLength,y=angledNumberLayerWidth,z=0.001);
        };
        hull() {
            translate([0,0,-1]) buildRectangularFrame(x=angledNumberLayerLength-recessforNumbered,y=angledNumberLayerWidth-recessforNumberedy,z=0.001+1);
            translate([0,-1,secondpanelupwardsNumber+1]) rotate([angleforNumbered,0,0]) 
                buildRectangularFrame(x=angledNumberLayerLength-recessforNumbered,y=angledNumberLayerWidth-recessforNumberedy,z=0.001+1);
               
        };

        translate([0,0,secondpanelupwardsNumber+1]) rotate([angleforNumbered,0,0]) translate([0,18.5,-2]) buildSwitchPlate(numberOfKeysLength=1);

    };
};

module buildRectangularFrame(x=0,y=0,z=0) {
    cube([
            x,
            y,
            z,
    ], center=true);
};

module buildGeneralCase() {
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

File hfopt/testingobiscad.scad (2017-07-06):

use <obiscad/attach.scad>
use <obiscad/vector.scad>

c1 = [[10,10,10], [0,0,1], 20];

connector(c1);
connector(a1);

echo(-[1,1,1]);

a1 = [[0,0,3], [1,0,1], 45];

cube([10,10,10]);

attach(c1, a1) 
union() {
    sphere(r=3,center=true);
    translate([0,-10,0]) cube([2,10,2]);
};

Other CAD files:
3DPrinting/microcontrollerholder.stl
hfopt/Untitled-595a0aec.stl
lets_splitFirmware/imgs/right.stl
hfopt/Untitled-59578781.stl
3DPrinting/keystem.scad
3DPrinting/dodgykeycaps.skp
3DPrinting/good shift key.skp
3DPrinting/microcontrollerholder.skp
hfopt/Untitled-5959bd14.stl
hfopt/Untitled-5959ca48.stl
hfopt/Untitled-5959ca69.stl
hfopt/obiscad-master/obiscad-master/examples/attach_01.scad
hfopt/obiscad-master/obiscad-master/examples/bcube_01_calibration_cube.scad
hfopt/obiscad-master/obiscad-master/examples/bcube_02_test_resolution.scad
hfopt/obiscad-master/obiscad-master/examples/bcube_03_cutouts.scad
hfopt/obiscad-master/obiscad-master/examples/bevel_01_concave_corner.scad
hfopt/obiscad-master/obiscad-master/examples/bevel_02_cube.scad
hfopt/obiscad-master/obiscad-master/examples/bevel_03_buttress.scad
hfopt/obiscad-master/obiscad-master/examples/vector_01.scad
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

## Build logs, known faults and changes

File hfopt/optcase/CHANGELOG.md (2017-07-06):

# Change Log
All notable changes to this project will be documented in this file. This change log follows the conventions of [keepachangelog.com](http://keepachangelog.com/).

## [Unreleased]
### Changed
- Add a new arity to `make-widget-async` to provide a different widget shape.

## [0.1.1] - 2017-07-03
### Changed
- Documentation on how to make the widgets.

### Removed
- `make-widget-sync` - we're all async, all the time.

### Fixed
- Fixed widget maker to keep working when daylight savings switches over.

## 0.1.0 - 2017-07-03
### Added
- Files from the new template.
- Widget maker public API - `make-widget-sync`.

[Unreleased]: https://github.com/your-name/optcase/compare/0.1.1...HEAD
[0.1.1]: https://github.com/your-name/optcase/compare/0.1.0...0.1.1

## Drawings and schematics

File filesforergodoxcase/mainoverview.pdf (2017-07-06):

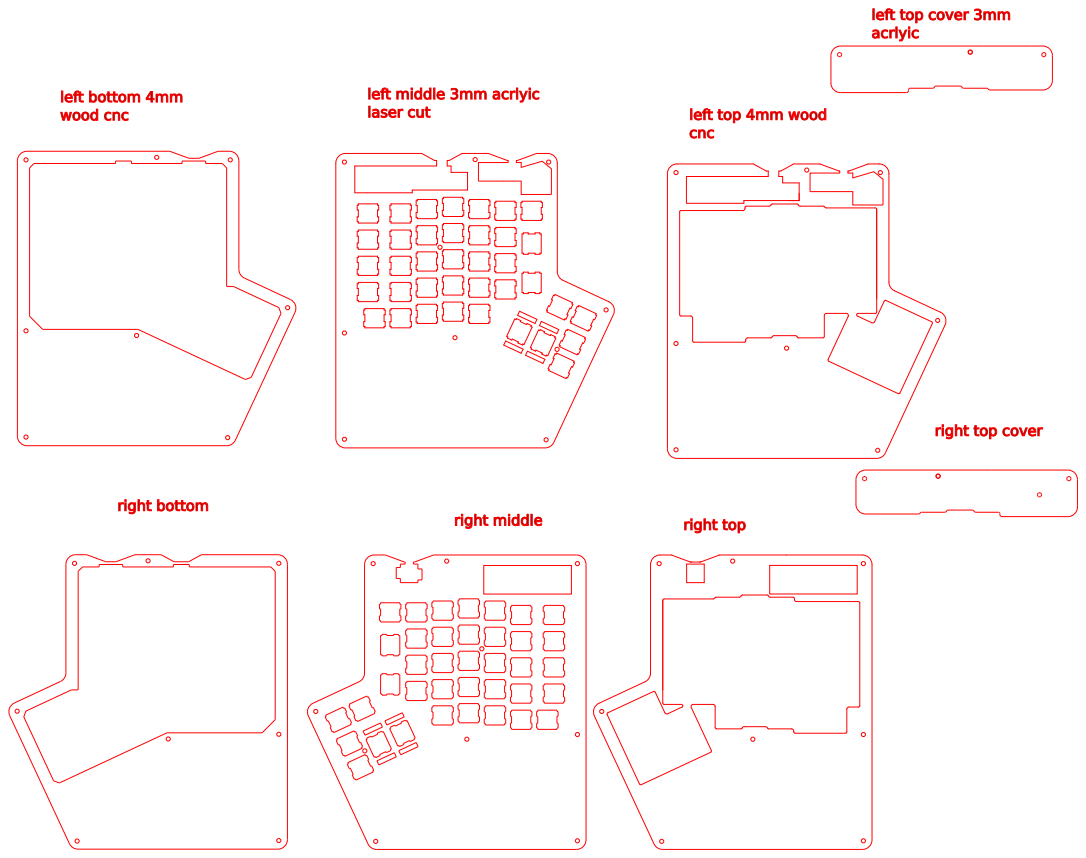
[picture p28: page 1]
left bottom 4mm wood cnc; laser cut; left top 4mm wood; cnc; right middle; right top; right bottom

left top cover 3mm
acrlyic

left middle 3mm acrlyic

right top cover

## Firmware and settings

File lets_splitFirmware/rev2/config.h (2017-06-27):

/*
Copyright 2012 Jun Wako <wakojun@gmail.com>

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
You should have received a copy of the GNU General Public License
along with this program.  If not, see <http://www.gnu.org/licenses/>.
*/

#ifndef CONFIG_H
#define CONFIG_H

#include "config_common.h"

/* USB Device descriptor parameter */
#define VENDOR_ID       0xFEED
#define PRODUCT_ID      0x3060
#define DEVICE_VER      0x0001
#define MANUFACTURER    HFrgrd
#define PRODUCT         hfvoy
#define DESCRIPTION     A split keyboard, interlocking, 85%

/* key matrix size */
// Rows are doubled-up
#define MATRIX_ROWS 12
#define MATRIX_COLS 18

// wiring of each half

// #define MATRIX_ROW_PINS { F5, F6, F7, B1, B3, B2} //leftside
// #define MATRIX_COL_PINS { D1, D4, C6, D7, E6, B4, B5, B6, F4 } //leftside

#define MATRIX_ROW_PINS { D1, F4, F5, F6, F7, B1} //rightside
#define MATRIX_COL_PINS { B3, B2, B6, B5, B4, E6, D7, C6, D4 } //rightside
// #define MATRIX_COL_PINS { D4, C6, D7, E6, B4, B5, B6, B2, B3 } //rightside flipped =bad

// #define MATRIX_COL_PINS { B6, B2, B3, B1, F7, F6 } //uncomment this line and comment line above if you need to reverse left-to-right key order

#define CATERINA_BOOTLOADER

/* COL2ROW or ROW2COL */
#define DIODE_DIRECTION COL2ROW

/* define if matrix has ghost */
//#define MATRIX_HAS_GHOST

/* number of backlight levels */
// #define BACKLIGHT_LEVELS 3

/* Set 0 if debouncing isn't needed */
#define DEBOUNCING_DELAY 5

/* Mechanical locking support. Use KC_LCAP, KC_LNUM or KC_LSCR instead in keymap */
#define LOCKING_SUPPORT_ENABLE
/* Locking resynchronize hack */
#define LOCKING_RESYNC_ENABLE

/* key combination for command */
#define IS_COMMAND() ( \
    keyboard_report->mods == (MOD_BIT(KC_LSHIFT) | MOD_BIT(KC_RSHIFT)) \
)

/* ws2812 RGB LED */
#define RGB_DI_PIN D3
#define RGBLIGHT_TIMER
#define RGBLED_NUM 12    // Number of LEDs
#define ws2812_PORTREG  PORTD
#define ws2812_DDRREG   DDRD

/*
 * Feature disable options
 *  These options are also useful to firmware size reduction.
 */

/* disable debug print */
// #define NO_DEBUG

/* disable print */
// #define NO_PRINT

/* disable action features */
//#define NO_ACTION_LAYER
//#define NO_ACTION_TAPPING
//#define NO_ACTION_ONESHOT
//#define NO_ACTION_MACRO
//#define NO_ACTION_FUNCTION


#endif

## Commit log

2017-06-07 The first commit
    [microcontrollerholder.skp, microcontrollerholder.stl]
2017-06-08 Delete overall printing svg
    the space causes confusion on linux so it is changed to overallprinting.
2017-06-14 Version 2: added holes for the arduino and trs jack. added four more mounting holes to avoid having to glue the layers
    [microcontrollerholder.skp]
2017-06-25 Started on the guide. And done added a few STLs for keycaps
    [dodgykeycaps.skp, good shift key.skp]
2017-06-26 Update on the read me guide and added structuring to files
    [dodgykeycaps.skp, good shift key.skp, microcontrollerholder.skp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]
2017-06-27 added firmware folder
    [left.stl, lets split rev2 case.iges, plate.stl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]
2017-06-30 started to work on hfopt
    [case.scad]
2017-07-01 working on case and added a couple of packages for attachment
    [attach.scad, attach_01.scad, bcube.scad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]
2017-07-06 added ergodone cases for j+d.
    [Untitled-59578781.stl, Untitled-5959bd14.stl, Untitled-5959bd23.stl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]
2017-07-06 added keycaps 3d printing
    [dsakeycap.scad, dsakeycap.stl, dsakeycap2.stl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]
2017-07-06 working on the bby
    [post-demo.scad]
2017-07-07 Improved the web connection function a lot.
    [post-demo.scad]
2017-07-08 made the edges work
    [post-demo.scad]
2017-07-09 more changes ya kjnow
    [post-demo.scad]

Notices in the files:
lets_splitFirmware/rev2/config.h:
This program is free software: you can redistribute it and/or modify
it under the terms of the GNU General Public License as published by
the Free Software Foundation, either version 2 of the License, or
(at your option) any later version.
